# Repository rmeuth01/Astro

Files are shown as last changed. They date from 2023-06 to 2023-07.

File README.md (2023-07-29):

# Astro: Jetson Nano Handheld


## Description
 
The Astro is an open-source gaming handheld based on the Jetson Nano single board computer.  It is designed with the goals of performance, ergonomics, and to be built using off the shelf components and 3D printed parts.  This was designed to fit my personal use case so there are some odd design choices, such as mono-only headphone output and lack of internal speaker.  

## Features

- Jetson Nano SOC
  - Quad-core ARM Cortex-A57 processor (Overclocked to 2.0 GHz)
  - NVIDIA Maxwell GPU with 128  CUDA cores
  - 4 GB LPDDR4
  - RTC Enabled with battery backup
- 800 x 480 (5:3 aspect ratio) display
- 10,000mAh battery, providing up to 6 hours of gameplay
- 5.0GHz IEEE 802.11b/g/n/ac wireless, Bluetooth 4.2
- Mono Audio Output via i2s MAX98357A audio amplifier
- Headphone jack
- USB 2.0 Host port, USB-C Charging Port
- Charging indicator
- 3D Printed housing and buttons.
- D-Pad, Action Buttons, Start, Select, Turbo and Hotkey buttons
- Dual stacked shoulder buttons (L, R, LZ, RZ)
- 2x switch analog sticks
- Mirrored controller PCBs with FFC cables based on ATMEGA32u4 internal USB 2.0 HID controller
- Size: 220mm x 121mm x 40mm, Weight: 639.5g (she chonky)
- Adjustable TDP: 5W, 10W Modes
- Safe software/hardware shutdown to prevent corruption to the SD card data (low voltage shutdown included)
- ARES Operating System ( https://techtoytinker.com/nvidia-jetson-nano )

### Credits

- Astro Designed and Built by Ryan Meuth (rmeuth01 / beernalytic / DocRobot)
- Controller Design and software based on Retro Lite CM4 by Dmcke5 and StonedEdge ( https://github.com/StonedEdge/Retro-Lite-CM4 )

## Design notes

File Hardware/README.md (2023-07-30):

# Astro Hardware
The hardware consists of mostly off-the-shelf components, [custom gamepad](Gamepad/), and 3D printed [housing](Housing/) and [buttons](Buttons/).  The 3D printed parts are designed to be easily printed on a mid-range consumer 3D printer like an Ender 3 or similar. Design files are availble in this folder, and STL files are available on [Printables](https://www.printables.com/model/537843-astro-jetson-nano-game-handheld).  
The off-the shelf components are listed in the table below.

| Item	| Vendor / Link	| Qty |	Unit Cost |	Line Total |
| --- | --- | --- | --- | --- |
| Jetson Nano 4GB | [Sparkfun](https://www.sparkfun.com/products/16271) | 1 | $149.00 |	$149.00 |
| 10Ah Battery Pack | [Sparkfun](https://www.sparkfun.com/products/15593) | 1	| $21.50 |	$21.50 |
| 5" Screen - 800 x 480 |	[Adafruit](https://www.adafruit.com/product/1680) | 1 |	$29.95 | $29.95 |
| Soft Tactile Buttons |	[Adafruit](https://www.adafruit.com/product/3101) |	1 | $1.95 |	$1.95 |
| i2s Audio Amplifier |	[Adafruit](https://www.adafruit.com/product/3006) |	1 |	$5.95 |	$5.95 |
| Power switch |	[Adafruit](https://www.adafruit.com/product/805) | 1	| $0.95 |	$0.95 |
| HDMI to TTL Board |	[Adafruit](https://www.adafruit.com/product/2218) |	1	| $29.95 |	$29.95 |
| DIY HDMI Straight |	[Adafruit](https://www.adafruit.com/product/3548) |	2 |	$6.50 |	$13.00 |
| DIY HDMI Ribbon Cable - 20cm | [Adafruit](https://www.adafruit.com/product/3561) | 1 | $1.95 |	$1.95 |
| SNES Rubber Kit |	[Console5](https://console5.com/store/snes-replacement-controller-silicone-rubber-carbon-dot-pads.html) |	2 |	$2.99 |	$5.98 |
| Switch Joysticks |	[Amazon](https://www.amazon.com/Replacement-Joystick-Nintendo-Original-Professional/dp/B08397JQZG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) |	1 |	$8.99 |	$8.99 |
| Wifi / BT M.2 Module (Intel 8265) |	[Amazon](https://www.amazon.com/Intel-Dual-Band-Wireless-Ac-8265/dp/B01MZA1AB2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) |	1	| $19.95 |	$19.95 |
| Wifi / BT Antenna (x2) |	[Digikey](https://www.digikey.com/en/products/detail/molex/2042811100/8020427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) |	2 | $2.72 |	$5.44 |
| Custom Gamepad | https://jlcpcb.com/ | 1 | $40.00 | $40.00 |

Approx. Total: $335

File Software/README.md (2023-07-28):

# Astro Handheld Software Configuration Notes

## Audio Configuration
Bluetooth - https://developer.nvidia.com/embedded/learn/tutorials/connecting-bluetooth-audio 
ARES - Uninstall ps3controller drivers  RetroPie-Setup / manage packages / drivers - uninstall ps3controller
```
sudo adduser aresuser bluetooth
```
https://retropie.org.uk/forum/topic/20338/tutorial-bluetooth-audio-on-retropie-v4-4-and-raspberry-pi-3-model-b 

Audio Amp - https://medium.com/@Smartcow_ai/a-jetson-device-for-all-your-audio-applications-6016d3f1dbe7 

> MAX98357A  Board -> Jetson Nano Pins
> LRC -> 35
> DIN -> 40
> BCLK -> 12
> GND -> GND
> VIN -> 3V
> GAIN -> 100K Resistor to VIN (3dB gain)

Missing DTB file? 
```
sudo cp -v /boot/tegra210-p3448-0000-p3449-0000-a02.dtb /boot/dtb/
```

## Battery

Initialization Procedure:
Charge: 5V@2A for 8 hours
Stabilize: 1 Hour
Discharge: 1A to 3.0V (stress --cpu 3)
Charge: 5V@2A for 8 hours

## ARES Configuration
[Download](https://drive.google.com/drive/folders/1u76jqUj7gES4nGkd9EwwaGZ9EF99VG0T?usp=sharing) - Login: aresuser thera
Setup - https://retropie.org.uk/docs/First-Installation/
[Adding Themes](https://wiki.recalbox.com/en/tutorials/frontend-customization/add-themes-into-emulationstation)

### Fixing Save States
- git stash, update ARES scripts, remove then reinstall retroarch.
- /opt/ares/configs/all/retroarch/states

### Adding TDP Settings
- Remove MAX from Automagic-fan 
- Add TDP entry to ARES settingsmenu gamelist.xml
- Create empty “power.rp” file
- Add script somewhere? (Copy bgmsetting)
- Add Power Icon

## Disable Updates
```
sudo apt remove update-manager
pkill update-notifier
sudo chmod -x /usr/bin/update-notifier
```
https://linuxhint.com/turn-off-snap-ubuntu/ 

## Disable Automatic Suspend
In Desktop search for Power menu, disable suspend.

https://linux-tips.us/how-to-disable-sleep-and-hibernation-on-ubuntu-server/
AND
```
gsettings set org.gnome.settings-daemon.plugins.power sleep-inactive-battery-timeout 0
gsettings set org.gnome.settings-daemon.plugins.power sleep-inactive-ac-timeout 0
```

## Emulator Config
### Saturn 
From Retroarena-Setup, install & compile standalone yabause
Error in threads.h - correct to unsigned long
Comment out git line in yabause.sh scritp, add dummy=true and re-install from RetroArena-Setup.

### Duckstation Controls
Download and Install SDL: https://wiki.libsdl.org/SDL2/Installation
Built SDL Tests - run controllermap
Copy map string to gamecontrollerdb.txt in /opt/ares/duckstation/database
Remap in Duckstation Controller Settings

### PPSSPP Controls
Update PPSSPP From RetroArena-Setup
Copy gamecontrollerdb.txt from above to /opt/ares/emulators/ppsspp/assets

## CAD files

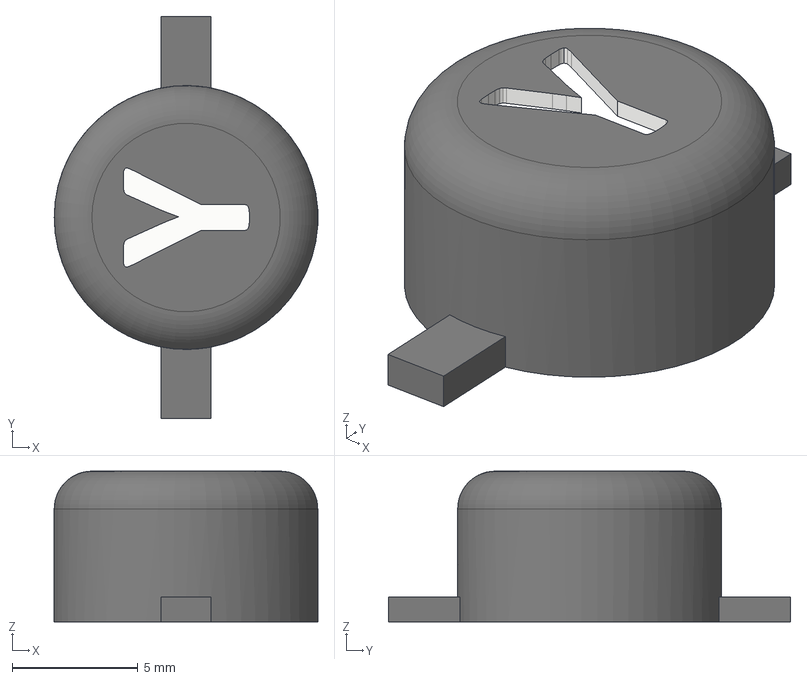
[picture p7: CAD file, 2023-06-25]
Hardware/Buttons/ButtonY.step
10.5 x 16.0 x 6.00 mm

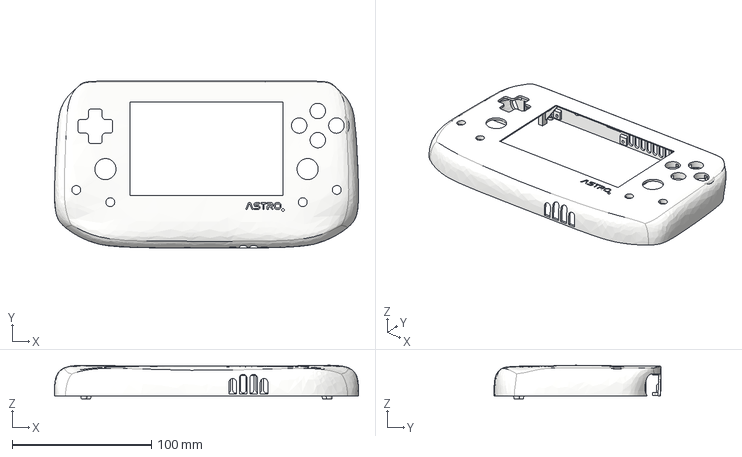
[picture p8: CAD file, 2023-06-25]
Hardware/Housing/Case Face.step
218.6 x 120.0 x 24.1 mm

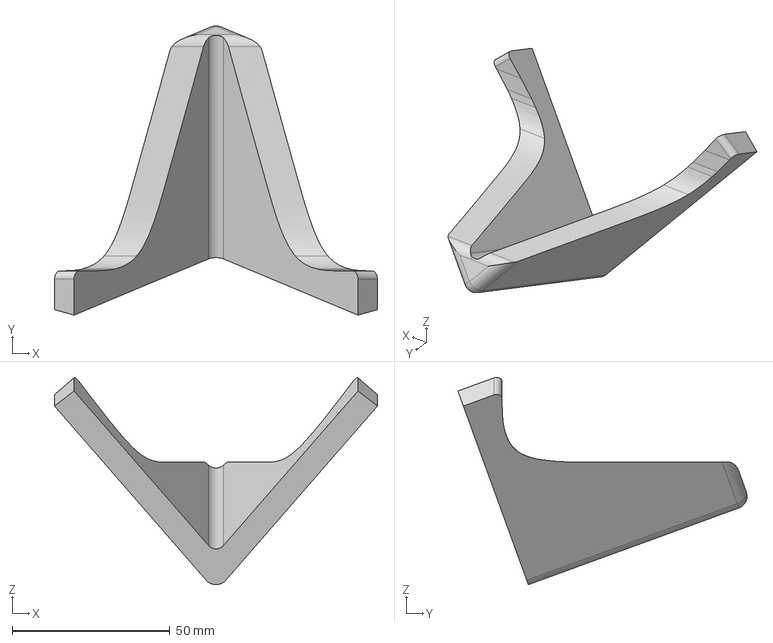
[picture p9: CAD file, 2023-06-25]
Hardware/Stand.step
102.4 x 91.7 x 65.7 mm

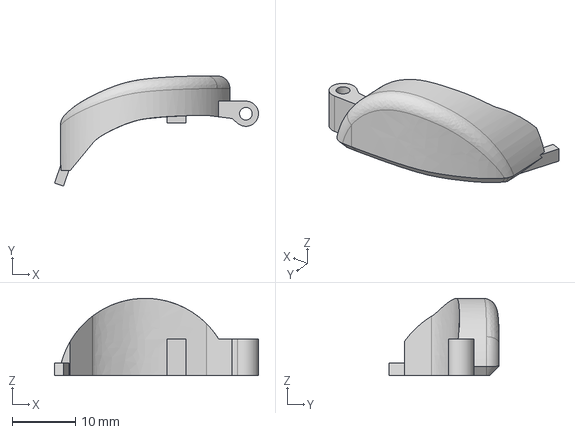
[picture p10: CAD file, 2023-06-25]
Hardware/Buttons/R2_Shoulder.step
32.3 x 17.5 x 12.2 mm

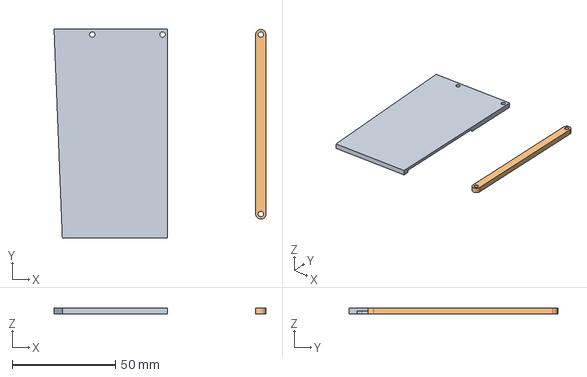
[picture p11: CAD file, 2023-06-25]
Hardware/Housing/IO Frame.step
102.6 x 101.3 x 3.00 mm

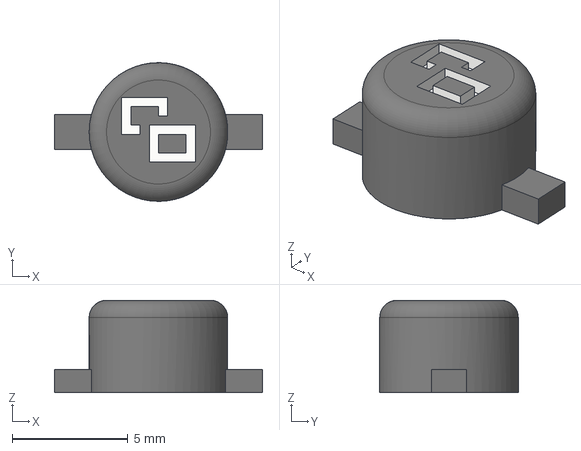
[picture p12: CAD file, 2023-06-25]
Hardware/Buttons/Function_Button_Menu.step
9.00 x 6.00 x 4.00 mm

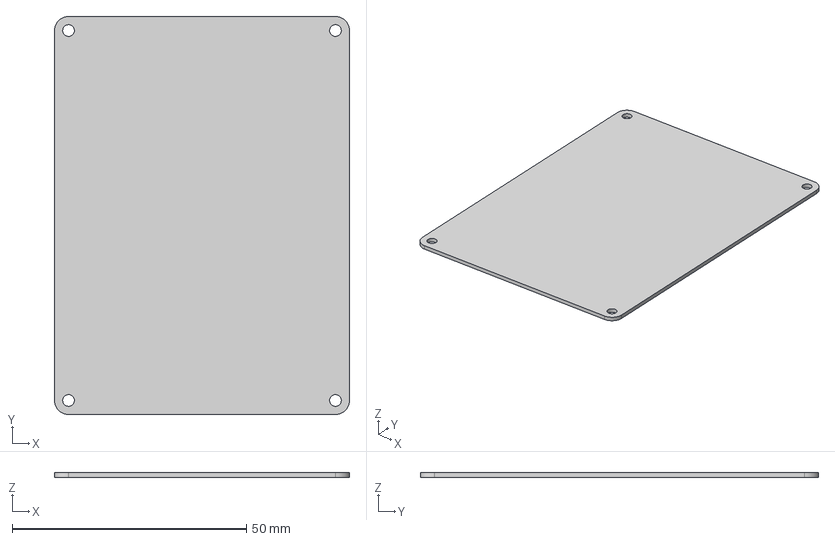
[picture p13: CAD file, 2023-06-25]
Hardware/Housing/Battery Plate.step
63.0 x 85.0 x 1.00 mm

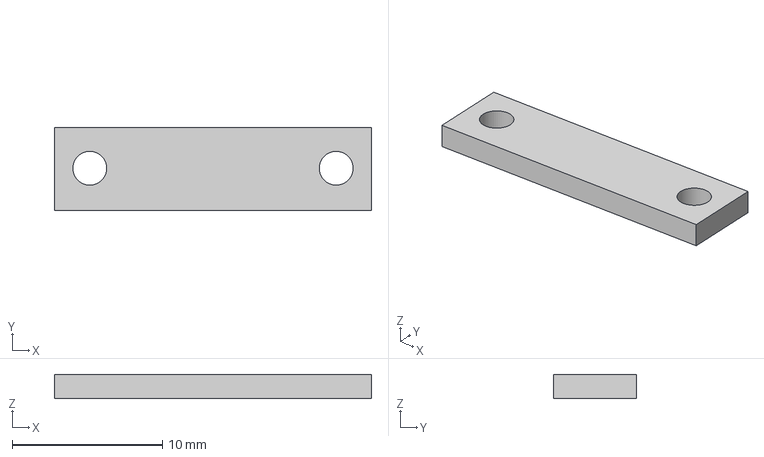
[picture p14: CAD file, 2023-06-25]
Hardware/Housing/Power Switch Retainer.step
21.1 x 5.50 x 1.60 mm

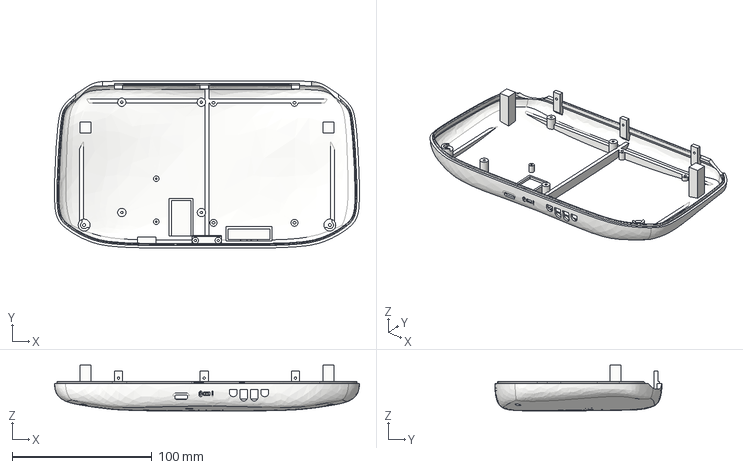
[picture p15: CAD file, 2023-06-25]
Hardware/Housing/Case Back.step
218.5 x 119.8 x 32.8 mm

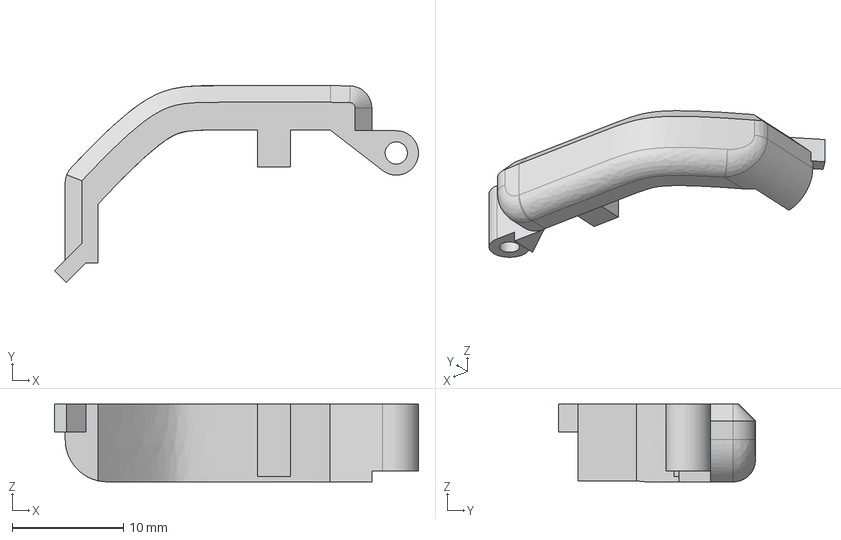
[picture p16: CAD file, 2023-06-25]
Hardware/Buttons/R1_Shoulder.step
32.8 x 17.8 x 7.00 mm

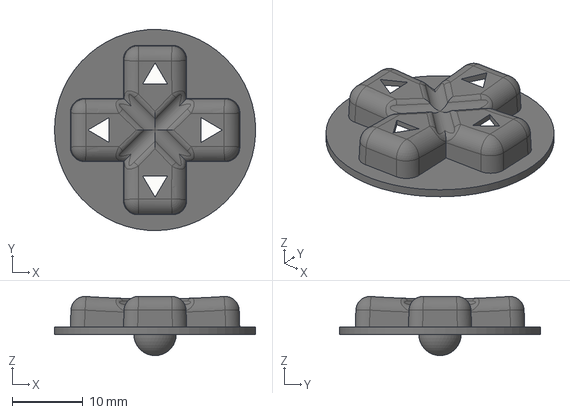
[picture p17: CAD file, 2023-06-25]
Hardware/Buttons/D-Pad.step
28.4 x 28.4 x 8.35 mm

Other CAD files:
Hardware/Buttons/Function_Button_Select.step
Hardware/Buttons/L2_Shoulder.step
Hardware/Buttons/Function_Button_Start.step
Hardware/Buttons/ButtonX.step
Hardware/Buttons/L1_Shoulder.step
Hardware/Buttons/ButtonA.step
Hardware/Buttons/ButtonB.step
Hardware/Buttons/Function_Button_Turbo.step
Hardware/Housing/Battery Plate.f3d
Hardware/Housing/Case Back.f3d
Hardware/Housing/Case Face.f3d
Hardware/Housing/IO Frame.f3d
Hardware/Housing/Power Switch Retainer.f3d

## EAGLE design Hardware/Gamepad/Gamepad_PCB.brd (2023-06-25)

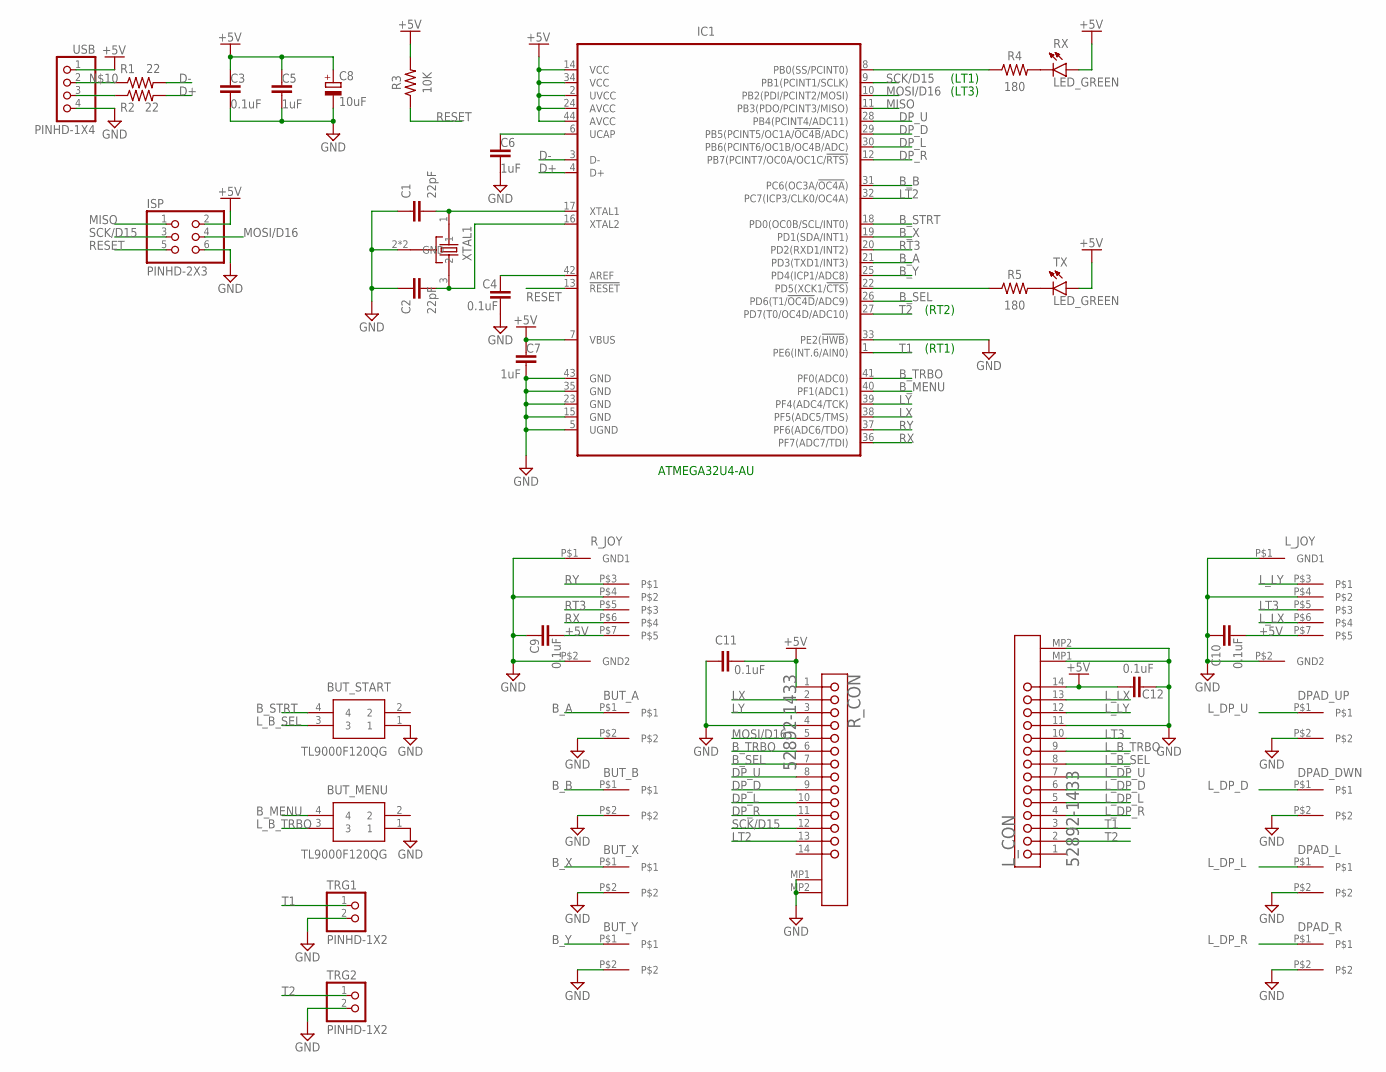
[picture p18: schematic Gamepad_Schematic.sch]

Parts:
BUT_A: MEMBRANEBUTTON
BUT_B: MEMBRANEBUTTON
BUT_MENU: TL9000F120QG
BUT_START: TL9000F120QG
BUT_X: MEMBRANEBUTTON
BUT_Y: MEMBRANEBUTTON
C1, C2: 22pF; CAPC1608X85
C3, C4, C9, C10, C11, C12: 0.1uF; CAPC2012X110
C5, C6, C7: 1uF; CAPC2012X110
C8: 10uF; CAPMP3216X180N
DPAD_DWN: MEMBRANEBUTTON
DPAD_L: MEMBRANEBUTTON
DPAD_R: MEMBRANEBUTTON
DPAD_UP: MEMBRANEBUTTON
IC1: ATMEGA32U4-AU; QFP80P1200X1200X120-44; MPN ATmega32U4-AU
ISP: PINHD-2X3; 2X03
L_CON: MOLEX_52892-1433MOLEX_52892-1433_0_0; MOLEX_52892-1433_0
L_JOY: 0545500571
R1, R2: 22; RESC2012X65
R3: 10K; RESC2012X65
R4, R5: 180; RESC2012X65
RX: LED_GREEN; LEDC1608X55N_FLAT-G
R_CON: MOLEX_52892-1433MOLEX_52892-1433_0_0; MOLEX_52892-1433_0
R_JOY: 0545500571
TRG1, TRG2: PINHD-1X2; 1X02
TX: LED_GREEN; LEDC1608X55N_FLAT-G
USB: PINHD-1X4; 1X04
XTAL1: ABM3BDIAG; OSCCC500X320X110

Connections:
+5V: C3.1, C5.1, C7.1, C8.1 (+), C9.2, C10.2, C11.2, C12.2, IC1.2 (UVCC), IC1.7 (VBUS), IC1.14 (VCC), IC1.24 (AVCC), IC1.34 (VCC), IC1.44 (AVCC), ISP.2, L_CON.14, L_JOY.P$7, R3.2, RX.A, R_CON.1, R_JOY.P$7, TX.A, USB.1
B_A: BUT_A.P$1, IC1.21 (PD3(TXD1/INT3))
B_B: BUT_B.P$1, IC1.31 (PC6(OC3A/!OC4A!))
B_MENU: BUT_MENU.4, IC1.40 (PF1(ADC1))
B_SEL: IC1.26 (PD6(T1/!OC4D!/ADC9)), R_CON.7
B_STRT: BUT_START.4, IC1.18 (PD0(OC0B/SCL/INT0))
B_TRBO: IC1.41 (PF0(ADC0)), R_CON.6
B_X: BUT_X.P$1, IC1.19 (PD1(SDA/INT1))
B_Y: BUT_Y.P$1, IC1.25 (PD4(ICP1/ADC8))
D+: IC1.4 (D+), R2.2
D-: IC1.3 (D-), R1.2
DP_D: IC1.29 (PB5(PCINT5/OC1A/!OC4B!/ADC)), R_CON.9
DP_L: IC1.30 (PB6(PCINT6/OC1B/OC4B/ADC)), R_CON.10
DP_R: IC1.12 (PB7(PCINT7/OC0A/OC1C/!RTS)), R_CON.11
DP_U: IC1.28 (PB4(PCINT4/ADC11)), R_CON.8
GND: BUT_A.P$2, BUT_B.P$2, BUT_MENU.1, BUT_START.1, BUT_X.P$2, BUT_Y.P$2, C1.1, C2.1, C3.2, C4.2, C5.2, C6.2, C7.2, C8.2 (-), C9.1, C10.1, C11.1, C12.1, DPAD_DWN.P$2, DPAD_L.P$2, DPAD_R.P$2, DPAD_UP.P$2, IC1.5 (UGND), IC1.15 (GND), IC1.23 (GND), IC1.33 (PE2(!HWB!)), IC1.35 (GND), IC1.43 (GND), ISP.6, L_CON.11, L_CON.MP1, L_CON.MP2, L_JOY.P$1 (GND1), L_JOY.P$2 (GND2), L_JOY.P$4, R_CON.4, R_CON.MP1, R_CON.MP2, R_JOY.P$1 (GND1), R_JOY.P$2 (GND2), R_JOY.P$4, TRG1.2, TRG2.2, USB.4, XTAL1.2 (GND), XTAL1.4 (GND)
LT2: IC1.32 (PC7(ICP3/CLK0/OC4A)), R_CON.13
LT3: L_CON.10, L_JOY.P$5
LX: IC1.38 (PF5(ADC5/TMS)), R_CON.2
LY: IC1.39 (PF4(ADC4/TCK)), R_CON.3
L_B_SEL: BUT_START.3, L_CON.8
L_B_TRBO: BUT_MENU.3, L_CON.9
L_DP_D: DPAD_DWN.P$1, L_CON.6
L_DP_L: DPAD_L.P$1, L_CON.5
L_DP_R: DPAD_R.P$1, L_CON.4
L_DP_U: DPAD_UP.P$1, L_CON.7
L_LX: L_CON.13, L_JOY.P$6
L_LY: L_CON.12, L_JOY.P$3
MISO: IC1.11 (PB3(PDO/PCINT3/MISO)), ISP.1
MOSI/D16: IC1.10 (PB2(PDI/PCINT2/MOSI)), ISP.4, R_CON.5
unnamed: C1.2, IC1.17 (XTAL1), XTAL1.1
unnamed: C6.1, IC1.6 (UCAP)
unnamed: R2.1, USB.3
unnamed: C2.2, IC1.16 (XTAL2), XTAL1.3 (2)
unnamed: C4.1, IC1.42 (AREF)
unnamed: R4.2, RX.C
unnamed: R5.2, TX.C
unnamed: IC1.8 (PB0(SS/PCINT0)), R4.1
unnamed: IC1.22 (PD5(XCK1/!CTS)), R5.1
unnamed: R1.1, USB.2
RESET: IC1.13 (!RESET), ISP.5, R3.1
RT3: IC1.20 (PD2(RXD1/INT2)), R_JOY.P$5
RX: IC1.36 (PF7(ADC7/TDI)), R_JOY.P$6
RY: IC1.37 (PF6(ADC6/TDO)), R_JOY.P$3
SCK/D15: IC1.9 (PB1(PCINT1/SCLK)), ISP.3, R_CON.12
T1: IC1.1 (PE6(INT.6/AIN0)), L_CON.3, TRG1.1
T2: IC1.27 (PD7(T0/OC4D/ADC10)), L_CON.2, TRG2.1

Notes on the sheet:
(LT1)
(LT3)
(RT1)
(RT2)

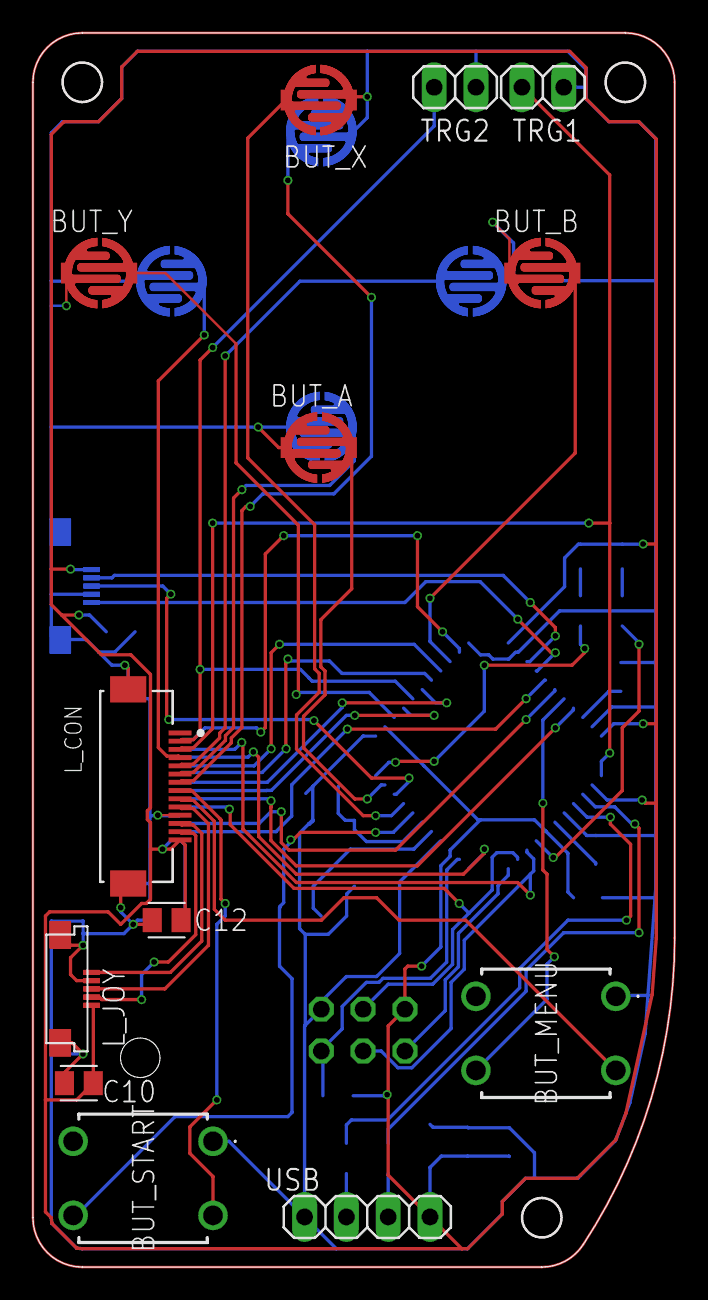
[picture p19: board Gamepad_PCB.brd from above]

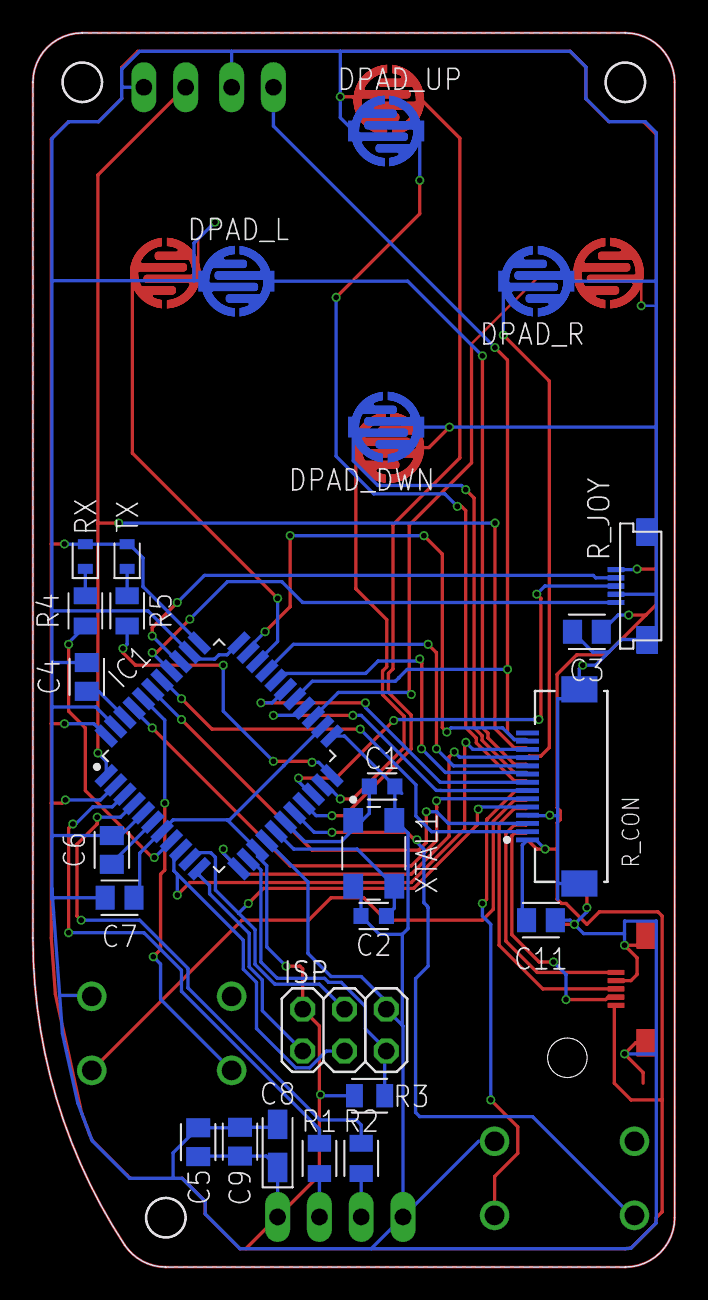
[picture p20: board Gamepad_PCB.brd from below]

Board: 2 copper layers, 39.0 x 75.0 mm, 39 parts (26 on the bottom side), 47 nets.

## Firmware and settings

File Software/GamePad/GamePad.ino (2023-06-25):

/*  
 * Ardupad for Atmega32u4
 * Default configuration - 2 Joysticks, 14 Buttons, 1 Hat Dpad.
 * 
 * Joystick calibration (currently disabled - comment in line 141 to enable):
 * 1: Press the Turbo and Start Buttons simultaneously to put the controller into calibration mode.
 * 2: Centre both joysticks and press the Menu Button to record mid position, RX LED will blink once to confirm step complete.
 * 3: Move both joysticks to full extents of travel several times to record maximum axis values.
 * 4: Press Menu   again. RX LED will blink once more to confirm.
 * 5: Calibration is now complete and stored.
 * 
 * If you're using this controller with Windows, you will also need to run the windows joypad calibration once you've completed the internal calibration.
 * If you change joysticks or your centerpoint drifts (thanks, nintendo) re-running the internal calibration should solve the problem.
 * 
 * Note: Whilst controller is in calibration mode all USB control output will cease until calibration is complete or controller is restarted.
 * 
 * Ardupad Created by - Daniel McKenzie
 * 10-03-2021 v1.3
 * Adapted by Ryan Meuth
 * - 
 * 2-10-2023
 */

#include <Joystick.h>  //https://github.com/MHeironimus/ArduinoJoystickLibrary
#include <EEPROM.h>

//Options
const bool cycleTimeTest = false;  //Enable to test CPU Cycle time.
#define baudrate 115200            //Baudrate for serial. Used only for polling rate test
#define LUT_BINS 380

//Define button pins
byte buttonCount = 14;                                                     //Number of buttons in use. Change length of buttonPins, lastButtonState and currentButtonState to match.
byte buttonPins[14] = { 1, 5, 2, 4, 15, 7, 13, 6, 12, 3, 16, 0, A4, A5 };  //Array to store digital pins used for buttons. Length must be the same as buttonCount.
byte dpadPins[4] = { 8, 11, 9, 10 };                                       //Up, Right, Down, Left. Do not change order of directions.

//Button state arrays
byte dpadPinsState[4];        //Empty State array for dPad
byte lastButtonState[14];     //Empty State array for buttons last sent state. Must be same length as buttonPins
byte currentButtonState[14];  //Empty State array for buttons. MMust be same length as buttonPins

//Define Analog Pins for joysticks
const int leftJoyX = A2;
const int leftJoyY = A3;
const int rightJoyX = A0;
const int rightJoyY = A1;

//Joystick Settings
const bool invertLeftY = true;       //------------------------------------------
const bool invertLeftX = false;       //Change these settings for Inverted mounting
const bool invertRightY = false;       //of joysticks.
const bool invertRightX = true;       //------------------------------------------
const int deadBandLeft = 10;          //
const int deadBandRight = 10;         //Joystick deadband settings. Deadband is the same for both axis on each joystick.
const bool useDeadband = true;        //
const int earlyLeftX = 30;            //--------------------------------------------------
const int earlyLeftY = 30;            //Distance from end of travel to achieve full axis movement.
const int earlyRightY = 30;           //This helps square out each axis response to allow full movement speed with direction input.
const int earlyRightX = 30;           //--------------------------------------------------
boolean scaledJoystickOutput = true;  //Enable joystick scaling. Needed for switch joysticks due to uneven axis travels. Disabling will save some compute time if your joystick works well without it.

//Main Joystick setup
Joystick_ Joystick(JOYSTICK_DEFAULT_REPORT_ID, JOYSTICK_TYPE_GAMEPAD,
                   buttonCount, 1,        // Button Count, Hat Switch Count
                   true, true, true,      // X Y Z
                   true, true, true,      // Rx, Ry, Rz
                   false, false,          // Rudder, Throttle
                   false, false, false);  // Accelerator, Brake, Steering

//Default Joystick calibration settings and EEPROM storage Address
int minLeftX = 157;  //EEPROM Adr = 1
int midLeftX = 496;  //EEPROM Adr = 5
int maxLeftX = 866;  //EEPROM Adr = 3

int minLeftY = 143;  //EEPROM Adr = 7
int midLeftY = 523;  //EEPROM Adr = 11
int maxLeftY = 905;  //EEPROM Adr = 9

int minRightY = 157;  //EEPROM Adr = 13
int midRightY = 491;  //EEPROM Adr = 17
int maxRightY = 910;  //EEPROM Adr = 15

int minRightX = 169;  //EEPROM Adr = 19
int midRightX = 536;  //EEPROM Adr = 23
int maxRightX = 870;  //EEPROM Adr = 21


//Joystick LookUp Tables, compiled at startup or after joystick calibration.
byte leftXLUT[LUT_BINS];
byte leftYLUT[LUT_BINS];
byte rightXLUT[LUT_BINS];
byte rightYLUT[LUT_BINS];

//All variables below general use, not used for configuration.
boolean calibrationMode = false;
int calibrationStep = 1;
long pollingTest;
float lastPollingMS;
long lastPollingReport;

void setup() {
  //Needed for Retropie to detect axis.
  Joystick.setXAxisRange(0, 254);
  Joystick.setYAxisRange(0, 254);
  Joystick.setZAxisRange(0, 254);
  Joystick.setRxAxisRange(0, 254);
  Joystick.setRyAxisRange(0, 2);
  Joystick.setRzAxisRange(0, 2);

  if (cycleTimeTest) {
    Serial.begin(baudrate);
    while (!Serial)
      ;  //Needed on 32u4 based arduinos for predictable serial output.
  }
  Joystick.begin(false);  //Initialise joystick mode with auto sendState disabled as it has a huge processor time penalty for seemingly no benefit.

  for (int i = 0; i < buttonCount; i++) {  //Set all button pins as input pullup. Change to INPUT if using external resistors.
    pinMode(buttonPins[i], INPUT_PULLUP);
  }
  for (int i = 0; i < 4; i++) {  //Set all dpad button pins as input pullup.
    pinMode(dpadPins[i], INPUT_PULLUP);
  }

  //eepromLoad();   //Check for stored joystick settings and load if applicable.
  rebuildLUTs();  //Build joystick LUT's from stored calibration values.
}

void loop() {
  buttonRead();
  if (!calibrationMode) {
    joypadButtons();
    joystickInput();
    //printJoystick();
    dPadInputAsHat();
    Joystick.sendState();  //Update input changes
  } else {
    joystickCalibration();
  }
  if (lastButtonState[13] == HIGH && lastButtonState[9] == HIGH) {  //If this combination of buttons is pressed, begin joystick calibration. (Turbo and Start)
    Serial.println("Calibration Mode Triggered");
    //calibrationMode = true;
  }
  if (cycleTimeTest) {
    pollingRateTest();
  }
  delay(10);
}

void rebuildLUTs() {
  joystickBuildLUT(leftXLUT, minLeftX, midLeftX, maxLeftX, earlyLeftX, deadBandLeft);
  joystickBuildLUT(leftYLUT, minLeftY, midLeftY, maxLeftY, earlyLeftY, deadBandLeft);
  joystickBuildLUT(rightXLUT, minRightX, midRightX, maxRightX, earlyRightX, deadBandRight);
  joystickBuildLUT(rightYLUT, minRightY, midRightY, maxRightY, earlyRightY, deadBandRight);
}

void pollingRateTest() {  //Reports current polling rate in MS every second.
  float pollingMS = (micros() - lastPollingMS) / 1000;
  lastPollingMS = micros();
  if (millis() > lastPollingReport + 1000) {  //If more than 1 second has passed:
    Serial.print(pollingMS);
    Serial.println("ms");
    lastPollingReport = millis();
  }
}

void buttonRead() {  //Read button inputs and set state arrays.
  for (int i = 0; i < buttonCount; i++) {
    int input = !digitalRead(buttonPins[i]);
    if (input != lastButtonState[i]) {
      lastButtonState[i] = input;
    }
  }
  for (int i = 0; i < 4; i++) {
    int input = !digitalRead(dpadPins[i]);
    if (input != dpadPinsState[i]) {
      dpadPinsState[i] = input;
    }
  }
}

void joypadButtons() {  //Set joystick buttons for USB output
  for (int i = 0; i < buttonCount; i++) {
    if (lastButtonState[i] != currentButtonState[i]) {
      Joystick.setButton(i, lastButtonState[i]);
      //Serial.print("Button: ");
      //Serial.println(i);
      currentButtonState[i] = lastButtonState[i];
    }
  }
}

void dPadInputAsAnalog() {      //D-Pad as RY and RZ Axis
  if (dpadPinsState[0] == 1) {  //Up
    Joystick.setRyAxis(2);
  } else if (dpadPinsState[2] == 1) {  //Down
    Joystick.setRyAxis(0);
  } else {
    Joystick.setRyAxis(1);
  }
  if (dpadPinsState[1] == 1) {  //Right
    Joystick.setRzAxis(2);
  } else if (dpadPinsState[3] == 1) {  //Left
    Joystick.setRzAxis(0);
  } else {
    Joystick.setRzAxis(1);
  }
}

void dPadInputAsHat() {
  int angle = -1;
  if (dpadPinsState[0] == 1) {  //Up
    if (dpadPinsState[1] == 1) {
      angle = 45;
    } else if (dpadPinsState[3] == 1) {
      angle = 315;
    } else {
      angle = 0;
    }
  } else if (dpadPinsState[2] == 1) {  //Down
    if (dpadPinsState[1] == 1) {
      angle = 135;
    } else if (dpadPinsState[3] == 1) {
      angle = 225;
    } else {
      angle = 180;
    }
  } else if (dpadPinsState[1] == 1) {  //Right
    angle = 90;
  } else if (dpadPinsState[3] == 1) {  //Left
    angle = 270;
  }
  Joystick.setHatSwitch(0, angle);
}

void eepromLoad() {                  //Loads stored settings from EEPROM
  if (readIntFromEEPROM(1) != -1) {  //Check Joystick Calibration in EEPROM is not Empty
    readJoystickConfig();            //Load joystick calibration from EEPROM
  }
}

void writeIntIntoEEPROM(int address, int number) {  //Splits Int into BYTES for EEPROM
  byte byte1 = number >> 8;
  byte byte2 = number & 0xFF;
  EEPROM.write(address, byte1);
  EEPROM.write(address + 1, byte2);
}

int readIntFromEEPROM(int address) {  //Converts BYTES to INT from EEPROM
  byte byte1 = EEPROM.read(address);
  byte byte2 = EEPROM.read(address + 1);
  return (byte1 << 8) + byte2;
}

void readJoystickConfig() {  //Read joystick calibration from EEPROM
                             //Left X
  minLeftX = readIntFromEEPROM(1);
  maxLeftX = readIntFromEEPROM(3);
  midLeftX = readIntFromEEPROM(5);
  //Left Y
  minLeftY = readIntFromEEPROM(7);
  maxLeftY = readIntFromEEPROM(9);
  midLeftY = readIntFromEEPROM(11);
  //Right Y
  minRightY = readIntFromEEPROM(13);
  maxRightY = readIntFromEEPROM(15);
  midRightY = readIntFromEEPROM(17);
  // Right X
  minRightX = readIntFromEEPROM(19);
  maxRightX = readIntFromEEPROM(21);
  midRightX = readIntFromEEPROM(23);
}

void writeJoystickConfig() {  //Store joystick calibration in EEPROM
                              //Left X
  writeIntIntoEEPROM(1, minLeftX);
  writeIntIntoEEPROM(3, maxLeftX);
  writeIntIntoEEPROM(5, midLeftX);
  //Left Y
  writeIntIntoEEPROM(7, minLeftY);
  writeIntIntoEEPROM(9, maxLeftY);
  writeIntIntoEEPROM(11, midLeftY);
  //Right Y
  writeIntIntoEEPROM(13, minRightY);
  writeIntIntoEEPROM(15, maxRightY);
  writeIntIntoEEPROM(17, midRightY);
  // Right X
  writeIntIntoEEPROM(19, minRightX);
  writeIntIntoEEPROM(21, maxRightX);
  writeIntIntoEEPROM(23, midRightX);
}

int readJoystick(int joystickPin, boolean invertOutput) {  //Reads raw joystick values and inverts if required
  int var = analogRead(joystickPin);
  if (invertOutput) {
    var = 1023 - var;
    return var;
  } else {
    return var;
  }
}

void joystickCalibration() {  //Very rough at the moment but it works. Read usage instructions at top of page.
  buttonRead();
  if (calibrationStep == 1) {
    if (lastButtonState[12] == 1) {
      RXLED1;
      delay(100);
      RXLED0;
      midLeftX = readJoystick(leftJoyX, invertLeftX);
      midLeftY = readJoystick(leftJoyY, invertLeftY);
      midRightX = readJoystick(rightJoyX, invertRightX);
      midRightY = readJoystick(rightJoyY, invertRightY);
      calibrationStep = 2;
    }
  } else if (calibrationStep == 2) {
    RXLED1;
    delay(100);
    RXLED0;
    minLeftX = midLeftX;
    minLeftY = midLeftY;
    maxLeftX = 0;
    maxLeftY = 0;
    minRightX = midRightX;
    minRightY = midRightY;
    maxRightX = 0;
    maxRightY = 0;
    calibrationStep = 3;
    delay(500);
  } else if (calibrationStep == 3) {
    int var = readJoystick(leftJoyX, invertLeftX);
    if (var > maxLeftX) maxLeftX = var;
    if (var < minLeftX) minLeftX = var;
    var = readJoystick(leftJoyY, invertLeftY);
    if (var > maxLeftY) maxLeftY = var;
    if (var < minLeftY) minLeftY = var;
    var = readJoystick(rightJoyX, invertRightX);
    if (var > maxRightX) maxRightX = var;
    if (var < minRightX) minRightX = var;
    var = readJoystick(rightJoyY, invertRightY);
    if (var > maxRightY) maxRightY = var;
    if (var < minRightY) minRightY = var;
    buttonRead();
    if (lastButtonState[12] == 1) {  //Complete Calibration
      RXLED1;
      delay(100);
      RXLED0;
      delay(200);
      writeJoystickConfig();  //Update EEPROM
      rebuildLUTs();
      calibrationStep = 1;
      calibrationMode = false;
    }
  }
}

void joystickBuildLUT(byte output[LUT_BINS], int minIn, int midIn, int maxIn, int earlyStop, int deadBand) {  //This function builds a lookup table for the given axis.
  //Shift all joystick values to a base of zero. All values are halved due to ram limitations on the 32u4.
  int shiftedMin = 0;
  int shiftedMid = (midIn - minIn) / 2;
  int shiftedMax = (maxIn - minIn) / 2;
  int temp;

  for (int i = 0; i < LUT_BINS; i++) {
    if (i < shiftedMid) {
      temp = map(i, shiftedMin + earlyStop, shiftedMid - deadBand, 0, 127);
      if (temp < 0) {
        temp = 0;
      } else if (temp > 254) {
        temp = 254;
      }
    } else {
      temp = map(i, shiftedMid + deadBand, shiftedMax - earlyStop, 127, 254);
      if (temp < 0) {
        temp = 0;
      } else if (temp > 254) {
        temp = 254;
      }
    }
    if (i < shiftedMid + deadBand && i > shiftedMid - deadBand) {
      temp = 127;
    }
    output[i] = temp;
  }
}

void printJoystick() {
  
  Serial.print("RY: ");
  Serial.print(readJoystick(rightJoyY, invertRightY));

  Serial.print(" RX: ");
  Serial.print(readJoystick(rightJoyX, invertRightX));

  Serial.print(" LY: ");
  Serial.print(readJoystick(leftJoyY, invertLeftY));

  Serial.print(" LX: ");
  Serial.println(readJoystick(leftJoyX, invertLeftX));

}

void joystickInput() {
  int var = 0;
  var = readJoystick(rightJoyY, invertRightY);
  var = (var - minRightY) / 2;
  Joystick.setRxAxis(rightYLUT[var]);

  var = readJoystick(rightJoyX, invertRightX);
  var = (var - minRightX) / 2;
  Joystick.setZAxis(rightXLUT[var]);

  var = readJoystick(leftJoyY, invertLeftY);
  var = (var - minLeftY) / 2;
  Joystick.setYAxis(leftYLUT[var]);

  var = readJoystick(leftJoyX, invertLeftX);
  var = (var - minLeftX) / 2;
  Joystick.setXAxis(leftXLUT[var]);
}

void joystickSimpleInput() {
  int var = 0;
  var = readJoystick(rightJoyY, invertRightY);
  var = (var/4)-1;
  Joystick.setRxAxis(var);

  var = readJoystick(rightJoyX, invertRightX);
  var = (var/4)-1;
  Joystick.setZAxis(var);

  var = readJoystick(leftJoyY, invertLeftY);
  var = (var/4)-1;
  Joystick.setYAxis(var);

  var = readJoystick(leftJoyX, invertLeftX);
  var = (var/4)-1;
  Joystick.setXAxis(var);
}

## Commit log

2023-06-25 Added Hardware and Software Files
    [Battery Plate.f3d, Battery Plate.step, Battery Plate.stl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]
2023-07-28 Update Hardware README.md
    Added Off-the shelf BOM.
2023-07-30 Moved STL files to Printables.
    [Battery Plate.stl, ButtonA.stl, ButtonB.stl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]
